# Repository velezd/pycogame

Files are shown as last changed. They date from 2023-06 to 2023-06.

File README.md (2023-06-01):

# pycoGame

pycoGame is a handheld game console based on Raspberry Pi Pico and a MicroPython library for easy game development inspired by pygame.

More information at http://zveleba.cz/pages/blog/posts/pycogame.html

## Content
- Open hardware game console
- MicroPython library pycogame
- Game launcher
- Example games
    - FlappyTux (Flappy Bird clone)
    - Micronoid (Arkanoid clone)
    - MicroMaze 3D (Raycaster maze game)
- Game development tools
    - precompile
    - img2rgb565

## Download

Version 1.0

## Installation

- Program firmware onto RPi Pico
    ./micropython/ports/rp2/build-PICO/firmware.uf2
- Copy game launcher files to RPi Pico flash.
  Easiest tool for that is Thonny IDE, also useful for debugging.
- Copy games to SD Card

## Build firmware

- Get submodules and build container

    `make setup`

- Build

    `make build`

- Cleanup (optional)

    `make cleanup`

## Pre-compile MicroPython scripts

MicroPython scripts can be pre-compiled for 
faster execution and reduced memory usage.

This will run the build container and execute `make setup` if needed.

`./precompile.sh games/Test/game.py`

## Convering images to RGB565 format

Requires python libraries `scikit-image` and `PIL` (on fedora: `sudo dnf install python3-scikit-image python3-pillow`).
Multiple images can be converted at once.
The script contains workaround for inaccurate colors on the LCD (gamma correction).

Convered images are stored in directory `converted` 
and gamma corrected images are kept in directory
`gamma_corrected`, so you can use them to sample the
final color value.

`./img2rgb565.py img1.png img2.png ...`

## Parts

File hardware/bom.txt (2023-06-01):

2.2" 240x320 TFT display, ILI9341, SPI  1x  https://www.laskarduino.cz/240x320-barevny-lcd-tft-displej-2-2--spi/
Li-ion charger, TP4056                  1x  https://www.laskarduino.cz/nabijecka-li-ion-clanku-tp4056-s-ochranou-microusb/
Speaker KSQG-706BP                      1x  https://www.gme.cz/magnetodynamicky-menic-do-dps-ksqg-706bp
Transistor PN2222A THT                  1x  https://www.gme.cz/bipolarni-tranzistor-pn2222a-to92
Resistor 1kohm THT ~0.4W                9x  
Resistor 200ohm THT ~0.4W               9x  
Tact switch THT 6x6x5mm                 7x  https://www.gme.cz/tc-0103-t
Diode MBR0520LT1G SMD SOD123            1x  https://www.gme.cz/dioda-mbr0520lt1g-smd
Slide switch B143-2 THT                 1x  https://www.gme.cz/posuvny-spinac-b143-2
Connector 4pin                          1x
Header 7x lcd female                    1x
Header 5x sd female                     1x
Header 20x rpi pico male                2x

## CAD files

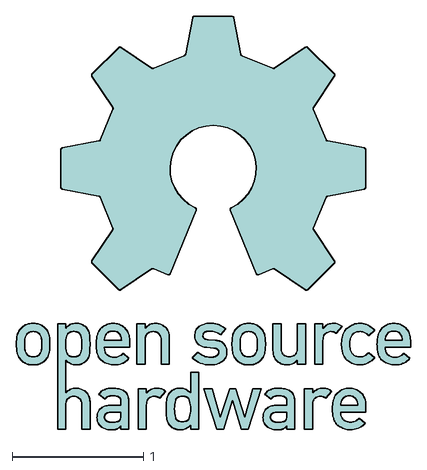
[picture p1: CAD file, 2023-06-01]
hardware/dxf/OSHW-Logo-R2000.dxf
3.00 x 3.15

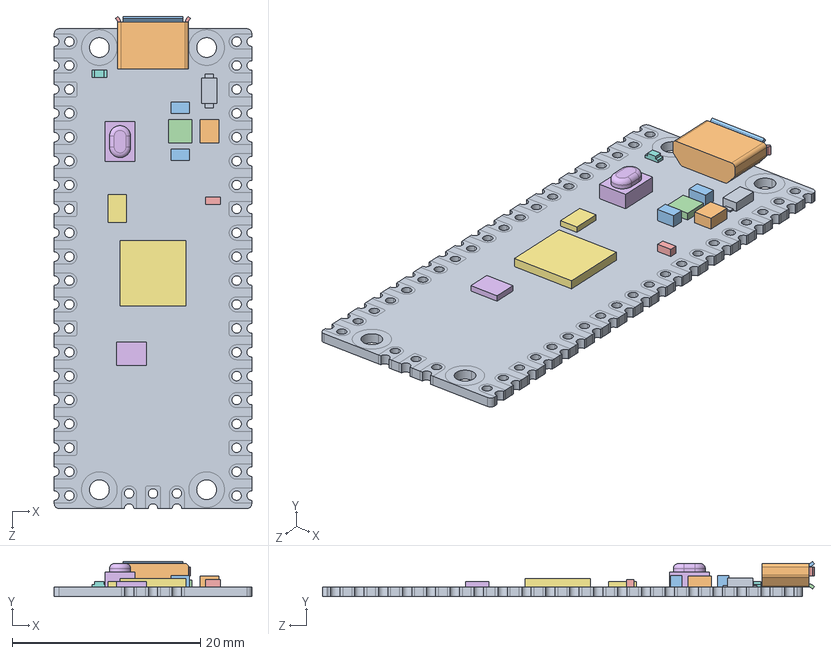
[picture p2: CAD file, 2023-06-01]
hardware/models/Pico-R3.step
21.0 x 3.73 x 52.3 mm
PICO_REF_BOARD.STEP
PICO_REF_USB.STEP
PICO_REF_SWITCH.STEP
PICO_REF_MICROCONTROLLER.STEP
PICO_REF_LED.STEP
PICO_REF_ONSEMI.STEP
PICO_BOURNS.STEP
PICO_MURATA.STEP x 2
PICO_RICHTEK.STEP
PICO_DIODES.STEP
PICO_AEL.STEP
PICO_WINBOND.STEP

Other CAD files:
hardware/dxf/pycogame_logo.dxf
code/games/MicroMaze 3D/source/intro.blend

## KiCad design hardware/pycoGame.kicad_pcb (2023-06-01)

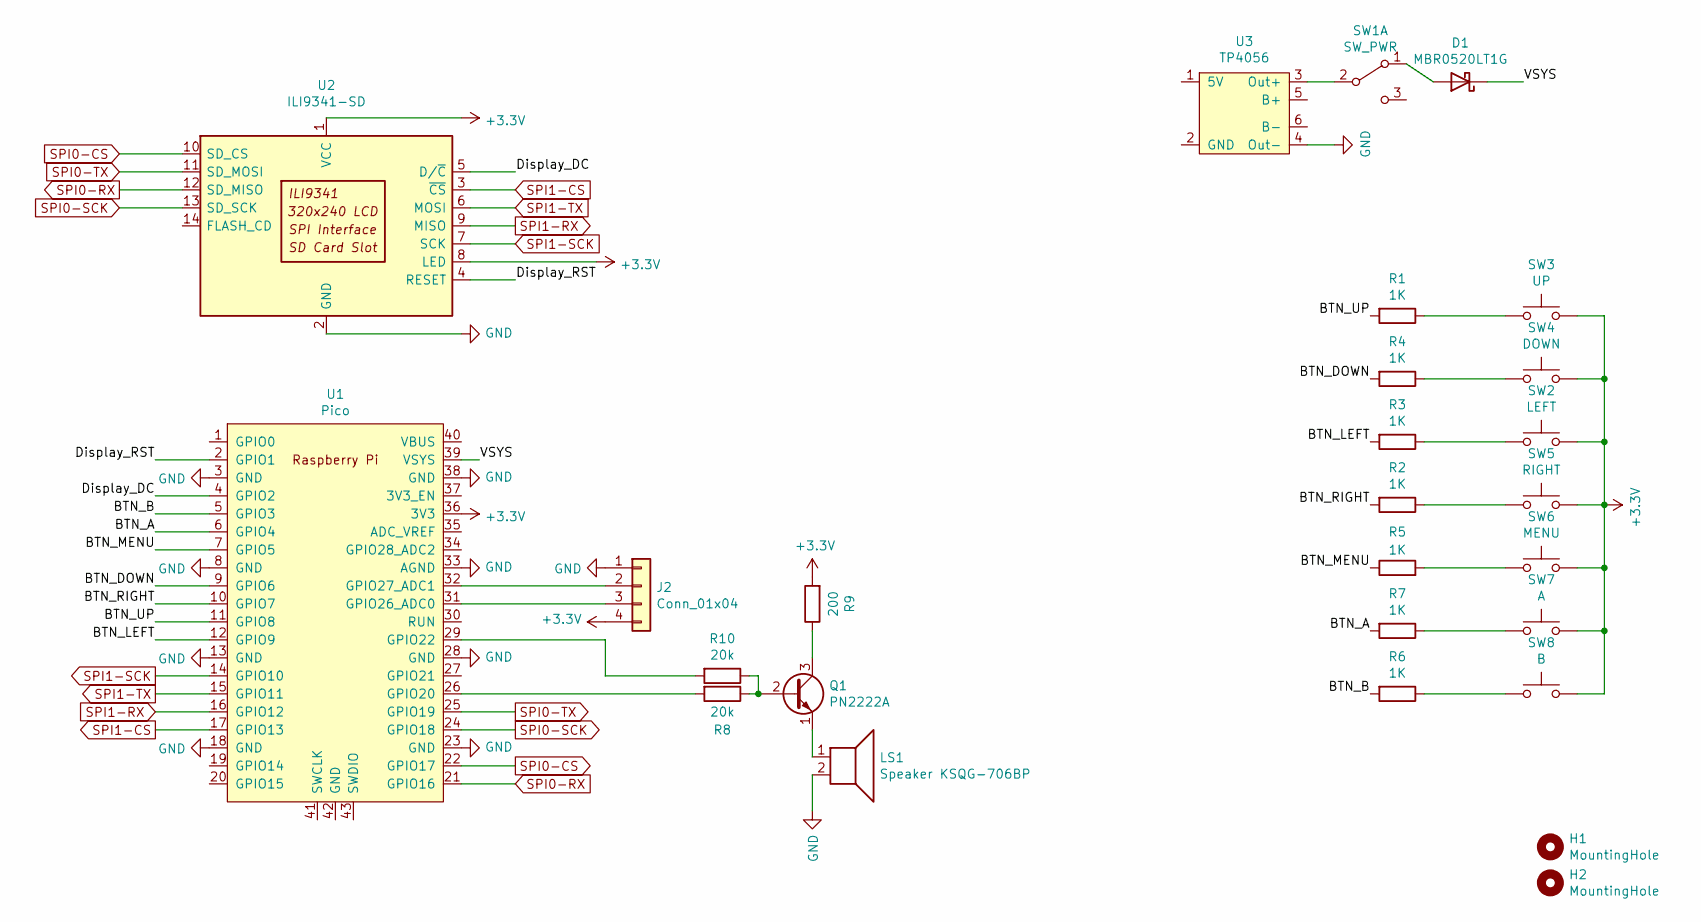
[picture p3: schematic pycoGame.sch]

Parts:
D1: MBR0520LT1G; D_SOD-123
H1, H2: MountingHole; MountingHole_3.2mm_M3_ISO14580_Pad
J2: Conn_01x04; PinHeader_1x04_P2.54mm_Vertical
LS1: Speaker KSQG-706BP; Speaker_KSQG-706BP
Q1: PN2222A; TO-92_Inline
R1, R2, R3, R4, R5, R6, R7: 1K; R_Axial_DIN0207_L6.3mm_D2.5mm_P7.62mm_Horizontal
R8, R10: 20k; R_Axial_DIN0207_L6.3mm_D2.5mm_P7.62mm_Horizontal
R9: 200; R_Axial_DIN0207_L6.3mm_D2.5mm_P7.62mm_Horizontal
SW1: SW_PWR; switch
SW2: LEFT; SW_PUSH_6mm_H5mm
SW3: UP; SW_PUSH_6mm_H5mm
SW4: DOWN; SW_PUSH_6mm_H5mm
SW5: RIGHT; SW_PUSH_6mm_H5mm
SW6: MENU; SW_PUSH_6mm_H5mm
SW7: A; SW_PUSH_6mm_H5mm
SW8: B; SW_PUSH_6mm_H5mm
U1: Pico; RPi_Pico_SMD_TH
U2: ILI9341-SD
U3: TP4056

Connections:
+3V3: J2.4, R9.2, SW2.1, SW3.2, SW4.2, SW5.1, SW6.2, SW7.2, SW8.2, U1.36 (3V3), U2.1 (VCC), U2.8 (LED)
/BTN_A: R7.2, U1.6 (GPIO4)
/BTN_B: R6.2, U1.5 (GPIO3)
/BTN_DOWN: R4.2, U1.9 (GPIO6)
/BTN_LEFT: R3.2, U1.12 (GPIO9)
/BTN_MENU: R5.1, U1.7 (GPIO5)
/BTN_RIGHT: R2.2, U1.10 (GPIO7)
/BTN_UP: R1.2, U1.11 (GPIO8)
/Display_DC: U1.4 (GPIO2), U2.5 (D/~C)
/Display_RST: U1.2 (GPIO1), U2.4 (RESET)
/VSYS: D1.1 (K), U1.39 (VSYS)
GND: J2.1, LS1.2, U1.3 (GND), U1.8 (GND), U1.13 (GND), U1.18 (GND), U1.23 (GND), U1.28 (GND), U1.33 (AGND), U1.38 (GND), U2.2 (GND), U3.4 (Out-)
unnamed: D1.2 (A), SW1.1 (A)
unnamed: J2.2, U1.32 (GPIO27_ADC1)
unnamed: J2.3, U1.31 (GPIO26_ADC0)
unnamed: LS1.1, Q1.1 (E)
unnamed: Q1.2 (B), R8.1, R10.1
unnamed: Q1.3 (C), R9.1
unnamed: R1.1, SW3.1
unnamed: R2.1, SW5.2
unnamed: R3.1, SW2.2
unnamed: R4.1, SW4.1
unnamed: R5.2, SW6.1
unnamed: R6.1, SW8.1
unnamed: R7.1, SW7.1
unnamed: R8.2, U1.26 (GPIO20)
unnamed: R10.2, U1.29 (GPIO22)
unnamed: SW1.2 (B), U3.3 (Out+)
SPI0-CS: U1.22 (GPIO17), U2.10 (SD_CS)
SPI0-RX: U1.21 (GPIO16), U2.12 (SD_MISO)
SPI0-SCK: U1.24 (GPIO18), U2.13 (SD_SCK)
SPI0-TX: U1.25 (GPIO19), U2.11 (SD_MOSI)
SPI1-CS: U1.17 (GPIO13), U2.3 (~CS)
SPI1-RX: U1.16 (GPIO12), U2.9 (MISO)
SPI1-SCK: U1.14 (GPIO10), U2.7 (SCK)
SPI1-TX: U1.15 (GPIO11), U2.6 (MOSI)

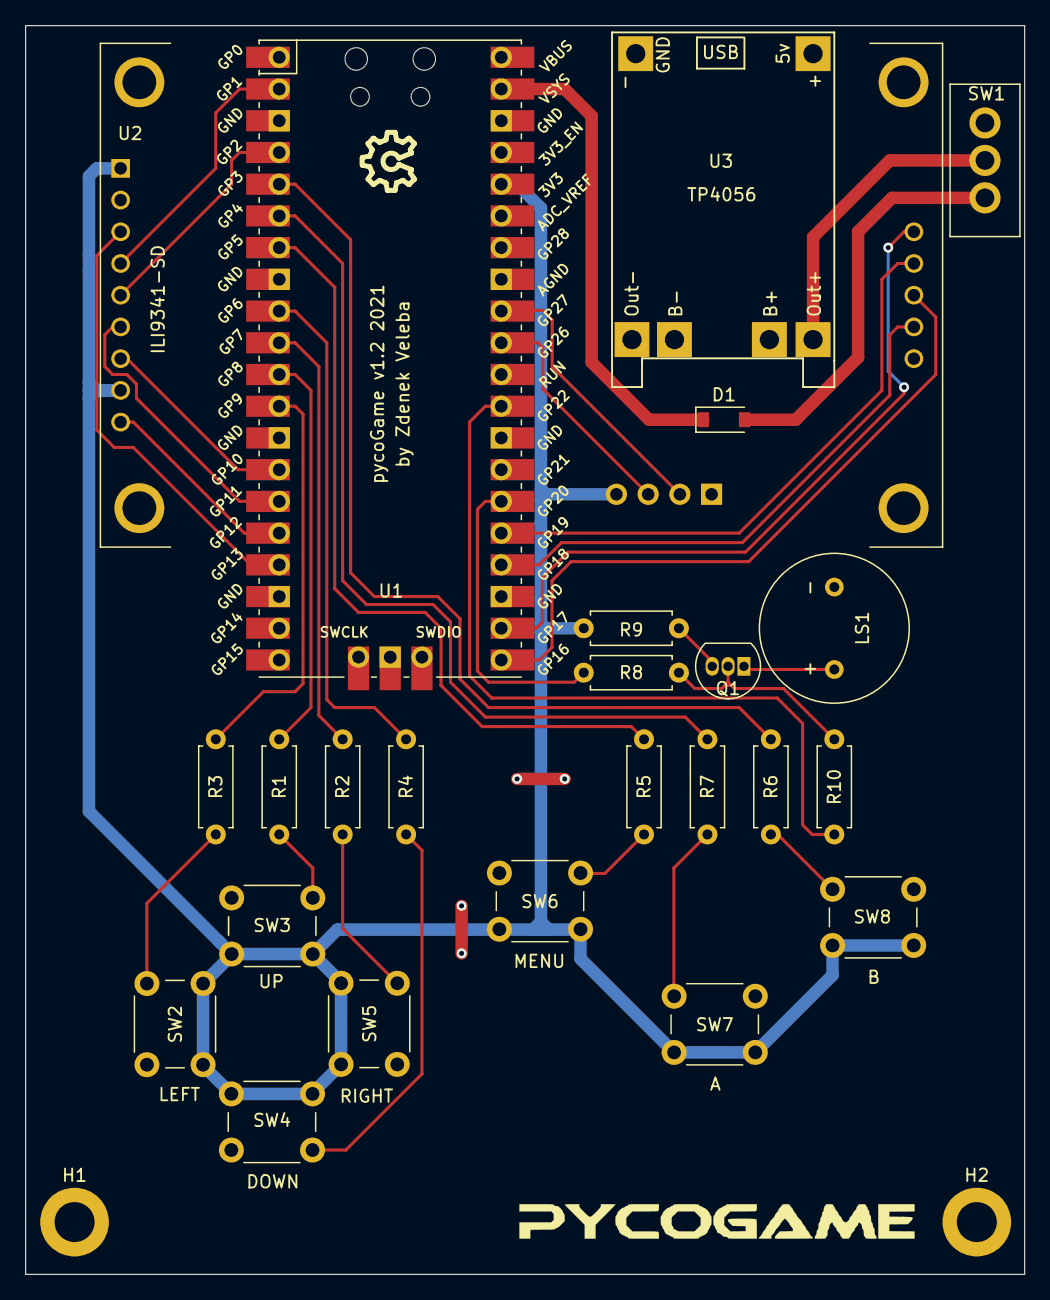
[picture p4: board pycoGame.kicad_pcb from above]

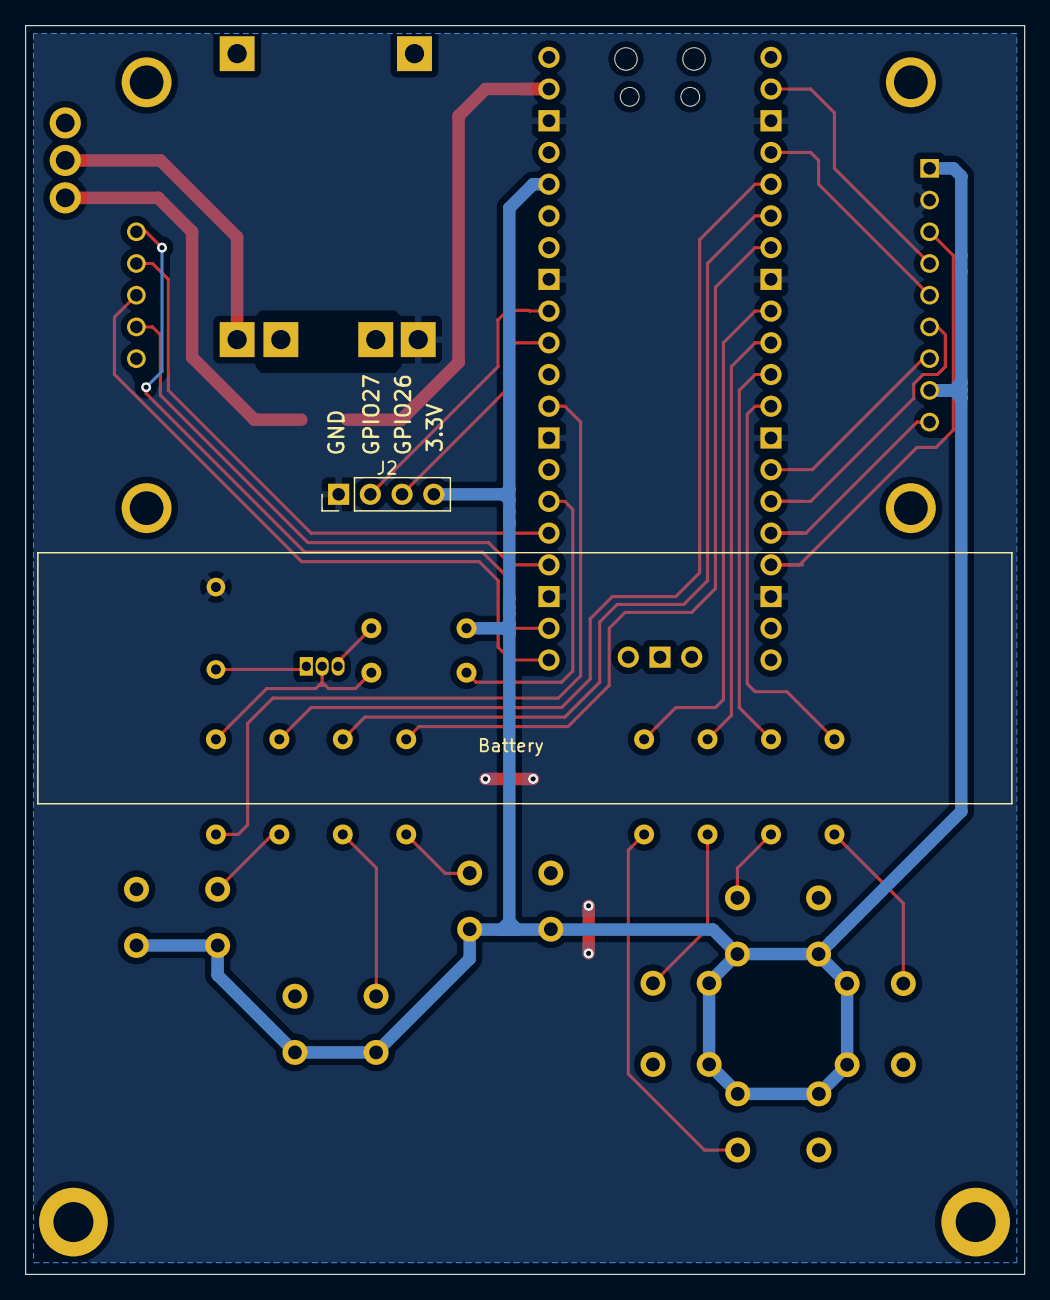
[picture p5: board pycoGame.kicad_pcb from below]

Board: 2 copper layers, 80.0 x 100.0 mm, 28 parts (2 on the bottom side), 36 nets.

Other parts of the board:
Battery: BatteryHolder 18650 no pads; BatteryHolder-18650-no-pads

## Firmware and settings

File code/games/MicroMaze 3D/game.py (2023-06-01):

from pycogame import Display, Clock, Sound, Input
from math import sin, cos
#from sdcard import SDCard
#from machine import Pin, SPI
import micropython
#import os
from gc import collect
from maze import generate_maze

#try:
#    sd_spi = SPI(0, baudrate=500000, sck=Pin(18), mosi=Pin(19), miso=Pin(16))
#    sd = SDCard(sd_spi, Pin(17))
#   os.mount(sd, '/sd', readonly=True)
#except OSError as e:
#    print(e)

display = Display()
clock = Clock()
sound = Sound()
input = Input()
display.clear()
collect()

########################################################################  Assets
tile_w = 6
tile_h = 200
tiles = [Display.load_sprite('./tiles/0.raw', tile_w,tile_h),
         Display.load_sprite('./tiles/1.raw', tile_w,tile_h),
         Display.load_sprite('./tiles/2.raw', tile_w,tile_h),
         Display.load_sprite('./tiles/3.raw', tile_w,tile_h),
         Display.load_sprite('./tiles/4.raw', tile_w,tile_h),
         Display.load_sprite('./tiles/5.raw', tile_w,tile_h),
         Display.load_sprite('./tiles/6.raw', tile_w,tile_h),
         Display.load_sprite('./tiles/7.raw', tile_w,tile_h),
         Display.load_sprite('./tiles/8.raw', tile_w,tile_h),
         Display.load_sprite('./tiles/9.raw', tile_w,tile_h),
         Display.load_sprite('./tiles/10.raw',tile_w,tile_h),
         Display.load_sprite('./tiles/11.raw',tile_w,tile_h),
         Display.load_sprite('./tiles/12.raw',tile_w,tile_h),
         Display.load_sprite('./tiles/13.raw',tile_w,tile_h),
         Display.load_sprite('./tiles/14.raw',tile_w,tile_h),
         Display.load_sprite('./tiles/15.raw',tile_w,tile_h),
         Display.load_sprite('./tiles/16.raw',tile_w,tile_h),
         Display.load_sprite('./tiles/17.raw',tile_w,tile_h),
         Display.load_sprite('./tiles/18.raw',tile_w,tile_h),
         Display.load_sprite('./tiles/19.raw',tile_w,tile_h),
         Display.load_sprite('./tiles/20.raw',tile_w,tile_h),
         Display.load_sprite('./tiles/21.raw',tile_w,tile_h),
         Display.load_sprite('./tiles/22.raw',tile_w,tile_h),
         Display.load_sprite('./tiles/23.raw',tile_w,tile_h),
         Display.load_sprite('./tiles/24.raw',tile_w,tile_h),
         Display.load_sprite('./tiles/25.raw',tile_w,tile_h),
         Display.load_sprite('./tiles/26.raw',tile_w,tile_h),
         Display.load_sprite('./tiles/27.raw',tile_w,tile_h),
         Display.load_sprite('./tiles/28.raw',tile_w,tile_h),
         Display.load_sprite('./tiles/29.raw',tile_w,tile_h),
         Display.load_sprite('./tiles/30.raw',tile_w,tile_h),
         Display.load_sprite('./tiles/31.raw',tile_w,tile_h),
         Display.load_sprite('./tiles/32.raw',tile_w,tile_h)]

gem = [Display.load_sprite('./gem/0.raw',32,32),
       Display.load_sprite('./gem/1.raw',16,16),
       Display.load_sprite('./gem/2.raw',8,8),
       Display.load_sprite('./gem/3.raw',2,2)]
# Precalculate gem y position on screen
gem_y = (int(tile_h/2-gem[0][2]/2),
         int(tile_h/2-gem[1][2]/2),
         int(tile_h/2-gem[2][2]/2),
         int(tile_h/2-gem[3][2]/2))
collect()
################################################################################

@micropython.native
def raycast(ray_lenght, step, ray_step_size, map_pos, map_w, map_h, gem_pos, gem_scale, map_list):
    hit_wall = False
    distance_wall = 0
    while not hit_wall and distance_wall < depth:
        if ray_lenght[0] < ray_lenght[1]:
            map_pos[0] += step[0]
            distance_wall = ray_lenght[0]
            ray_lenght[0] += ray_step_size[0]
        else:
            map_pos[1] += step[1]
            distance_wall = ray_lenght[1]
            ray_lenght[1] += ray_step_size[1]

        if (map_pos[0] >= 0 and map_pos[0] < map_w and
            map_pos[1] >= 0 and map_pos[1] < map_h):
            # Ray is in bounds so test to see if the ray cell is a wall block
            if map_list[map_pos[1]][map_pos[0]] == '#':
                hit_wall = True
            if map_list[map_pos[1]][map_pos[0]] == 'g':
                if distance_wall < 7:
                    gem_scale = int(distance_wall/2)
                else:
                    gem_scale = 3
                gem_pos.append((n, gem_y[gem_scale]))

    if distance_wall > depth:
        distance_wall = depth

    return (hit_wall, gem_pos, gem_scale, distance_wall)

def sound_tick_delay(max_dist, map_gem, player_x, player_y):
    dist = map_gem[0] * map_gem[1] - player_x * player_y
    return int(dist / max_dist * 2000)

################################################################  Initialization
soundt = 0
menu = True
map_list = []
gem_scale = 0

screen_buffer = [ 32 for _ in range(53) ]
new_buffer = screen_buffer.copy()

fov = 1
view_width = 318
depth = 8
depth_step = depth / 32
v_ray = [0.0, 0.0]
map_pos = [0, 0]
ray_step_size = [0.0, 0.0]

while True:
    if menu:
        # Main menu
        del map_list
        collect()
        display.draw_image('./intro.raw', 0, 0, 320, 200)
        intro_music = sound.load_song('Duke:d=16,o=5,b=180:8c,8d#,8p,8f,4p,8c,8f,8p,8g,4p,8c,8g,8p,8g#,8p,8c,8g#,8f,8d#,4c,8p,4d#,8p,8g,8c,8p')
        while True:
            dt = clock.tick()
            input.get_inputs(dt)
            sound.update(dt)

            if not sound.song_playing():
                sound.play_song(intro_music)

            if input.a_pressed:
                map_cell_w = 7
                map_cell_h = 7
                break
            if input.b_pressed:
                map_cell_w = 15
                map_cell_h = 15
                break

        del intro_music
        display.draw_image('./loading.raw', 100, 78, 112, 34)
        collect()

        # Actual map size
        map_w = map_cell_w * 2 + 1
        map_h = map_cell_h * 2 + 1
        # Generate map
        map_list = generate_maze(map_cell_w, map_cell_h)
        # Add gem to map
        map_gem = (map_w-2, map_h-2)
        map_list[map_gem[0]][map_gem[1]] = 'g'
        gem_max_dist = map_gem[0] * map_gem[1] - 1
        # Init player location
        player_x, player_y, player_angle = (1.1, 1.1, 0.7851)
        menu = False
        collect()

    # Game loop
    dt = clock.tick()
    input.get_inputs(dt)
    sound.update(dt)

    # Controls
    if input.up_on:
        x = player_x + sin(player_angle) * 0.005 * dt
        y = player_y + cos(player_angle) * 0.005 * dt
        if map_list[int(y)][int(x)] != '#':
            player_x = x
            player_y = y
    if input.down_on:
        x = player_x - sin(player_angle) * 0.005 * dt
        y = player_y - cos(player_angle) * 0.005 * dt
        if map_list[int(y)][int(x)] != '#':
            player_x = x
            player_y = y
    if input.left_on:
        player_angle -= 0.002 * dt
    if input.right_on:
        player_angle += 0.002 * dt

    # Found gem
    if int(player_x) == map_w-2 and int(player_y) == map_h-2:
        menu = True

    gem_pos = []
    for n in range(0, view_width, tile_w):
        # For each column calculate the projected ray angle on to world space
        ray_angle = (player_angle - fov / 2) + (n / view_width * fov)
        distance_wall = 0
        hit_wall = False
        # Unit vector for ray in player space
        v_ray = [sin(ray_angle), cos(ray_angle)]

        # DDA raycaster - https://lodev.org/cgtutor/raycasting.html
        # https://www.youtube.com/watch?v=NbSee-XM7WA
        # https://www.youtube.com/watch?v=xW8skO7MFYw
        ray_step_size = (0 if v_ray[1] == 0 else ( 1 if v_ray[0] == 0 else abs(1 / v_ray[0])),
                         0 if v_ray[0] == 0 else ( 1 if v_ray[1] == 0 else abs(1 / v_ray[1])))
        map_pos = [int(player_x), int(player_y)]
        
        # Determine direction and initial ray lenght
        if v_ray[0] < 0:
            step = [-1]
            ray_lenght = [(player_x - map_pos[0]) * ray_step_size[0]]
        else:
            step = [1]
            ray_lenght = [(map_pos[0] + 1 - player_x) * ray_step_size[0]]
        if v_ray[1] < 0:
            step.append(-1)
            ray_lenght.append((player_y - map_pos[1]) * ray_step_size[1])
        else:
            step.append(1)
            ray_lenght.append((map_pos[1] + 1 - player_y) * ray_step_size[1])

        hit_wall, gem_pos, gem_scale, distance_wall = raycast(ray_lenght, step, ray_step_size, map_pos, map_w, map_h, gem_pos, gem_scale, map_list)
    
        # draw walls
        if hit_wall:
            new_buffer[int(n/tile_w)] = int(distance_wall/depth_step)
        else:
            new_buffer[int(n/tile_w)] = 32

    # Draw walls
    for c,t in enumerate(new_buffer):
        if t != screen_buffer[c]:
            try:
                display.draw_sprite(tiles[t], c * tile_w, 0)
            except IndexError:
                print(t, c)
                display.draw_sprite(tiles[t], c * tile_w, 0)
    
    # Draw gem
    if gem_pos != []:
        mid = int(len(gem_pos)/2)
        if gem_pos[mid][0] + gem[gem_scale][1] < view_width:
            display.draw_sprite(gem[gem_scale], gem_pos[mid][0], gem_pos[mid][1])

        # Mark walls where the gem was for redraw
        for wx in range(int(gem_pos[mid][0]/tile_w),
                        int((gem_pos[mid][0] + gem[gem_scale][1])/tile_w)+1,
                        1):
            if wx < len(new_buffer):
                new_buffer[wx] = -1

    screen_buffer = new_buffer.copy()

    # Make sound tick
    soundt += dt   
    if soundt > sound_tick_delay(gem_max_dist, map_gem, player_x, player_y):
        sound.play_effect([1,[(400,1)]])
        soundt = 0

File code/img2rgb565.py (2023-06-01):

#!/usr/bin/python
""" Utility to convert images to raw RGB565 format """

from PIL import Image
from skimage import exposure, io
from struct import pack
from os import path, mkdir
import sys


def error(msg):
    """ Display error and exit """
    print (msg)
    sys.exit(-1)


def write_bin(f, pixel_list):
    """ Save image in RGB565 format """
    for pix in pixel_list:
        r = (pix[0] >> 3) & 0x1F
        g = (pix[1] >> 2) & 0x3F
        b = (pix[2] >> 3) & 0x1F
        f.write(pack('>H', (r << 11) + (g << 5) + b))


def adjust_gamma(in_path, num):
    """ Creates copy of image with adjusted gamma

    :param in_path: Path to image file
    :type in_path: str
    :param num: Gamma correction
    :type num: float
    :return: Path to modified file
    :rtype: str
    """
    modified_dir = path.join(path.dirname(path.abspath(in_path)), 'gamma_corrected')
    if not path.isdir(modified_dir):
        mkdir(modified_dir)

    filename, ext = path.splitext(path.basename(in_path))
    img = io.imread(in_path)
    gamma_corrected = exposure.adjust_gamma(img, num)
    new = path.join(modified_dir, filename + '.png')
    io.imsave(new, gamma_corrected)

    return new

if __name__ == '__main__':
    args = sys.argv
    if len(args) < 2:
        error('Please specify input file: ./img2rgb565.py test.png')

    new_dir = path.join(path.dirname(path.abspath(args[1])), 'converted')
    if not path.isdir(new_dir):
        mkdir(new_dir)
    
    for in_path in args[1:]:

        if not path.exists(in_path):
            error('File Not Found: ' + in_path)

        in_path = adjust_gamma(in_path, 1.5)
        filename, ext = path.splitext(in_path)
        filename = path.basename(filename)

        out_path = path.join(new_dir, filename + '.raw')
        img = Image.open(in_path)
        pixels = list(img.getdata().convert('RGB'))

        with open(out_path, 'wb') as f:
            write_bin(f, pixels)

        print('Saved: ' + out_path)
